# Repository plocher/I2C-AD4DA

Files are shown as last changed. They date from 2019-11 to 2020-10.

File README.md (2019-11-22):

# I2C-AD4DA
## License: CERN Open Hardware Licence v1.2

## Status: mature

I2C 4x A/D 1x  D/A I/O expander based on a PCF8591T

Expansion card that provides four Analog to Digital inputs and one digital to analog output.
I use it to control LED Layout lighting color balances and levels with slide potentiometers.

## Versions:
 * 1.0
 * 1.1
 * 2.0
 * 3.0

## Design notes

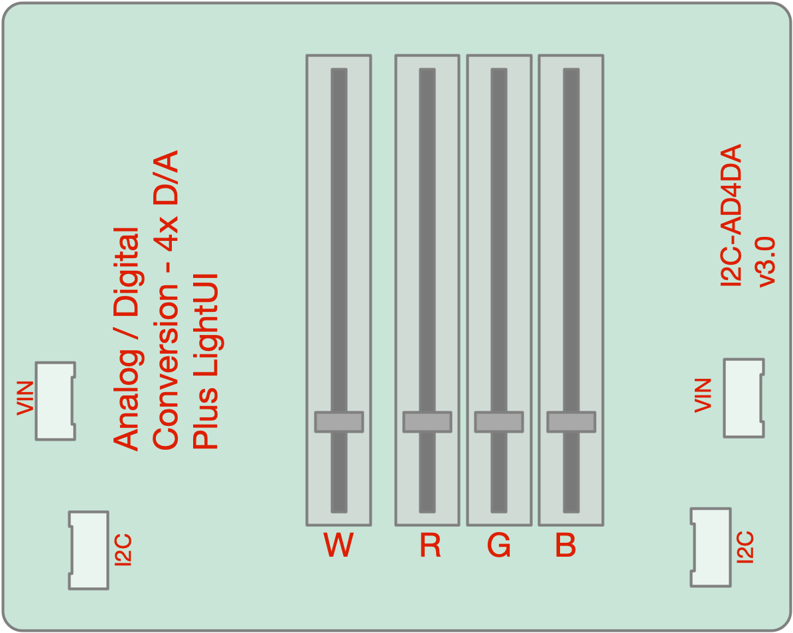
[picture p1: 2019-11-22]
I2C-AD4DA-LightUI-V3-Graphic.png

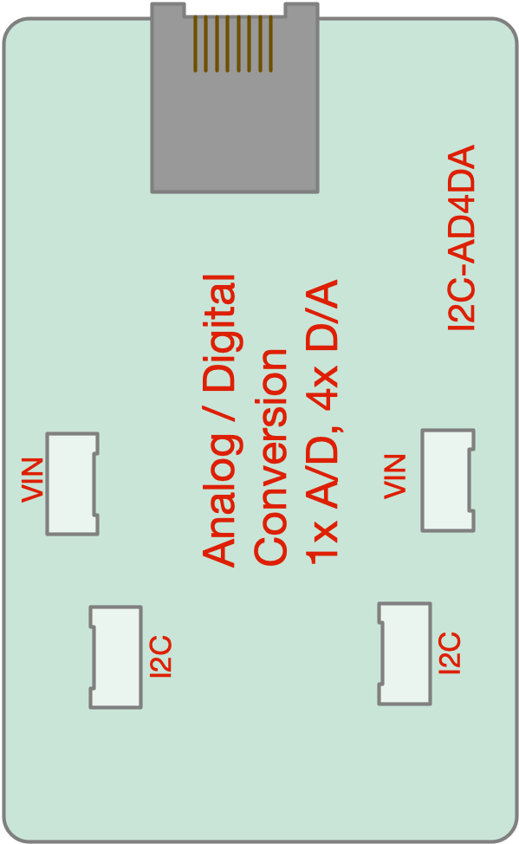
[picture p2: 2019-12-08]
I2C-AD4DA-V2-Graphic.png

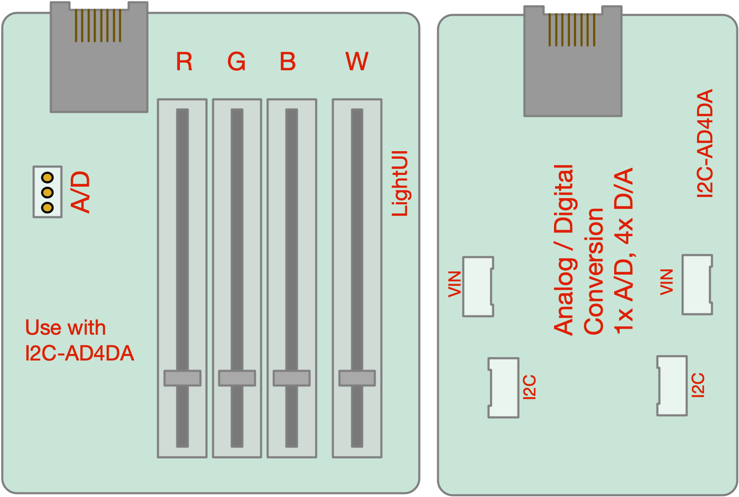
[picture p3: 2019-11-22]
I2C-AD4DA-LightUI-V2-Graphic.png

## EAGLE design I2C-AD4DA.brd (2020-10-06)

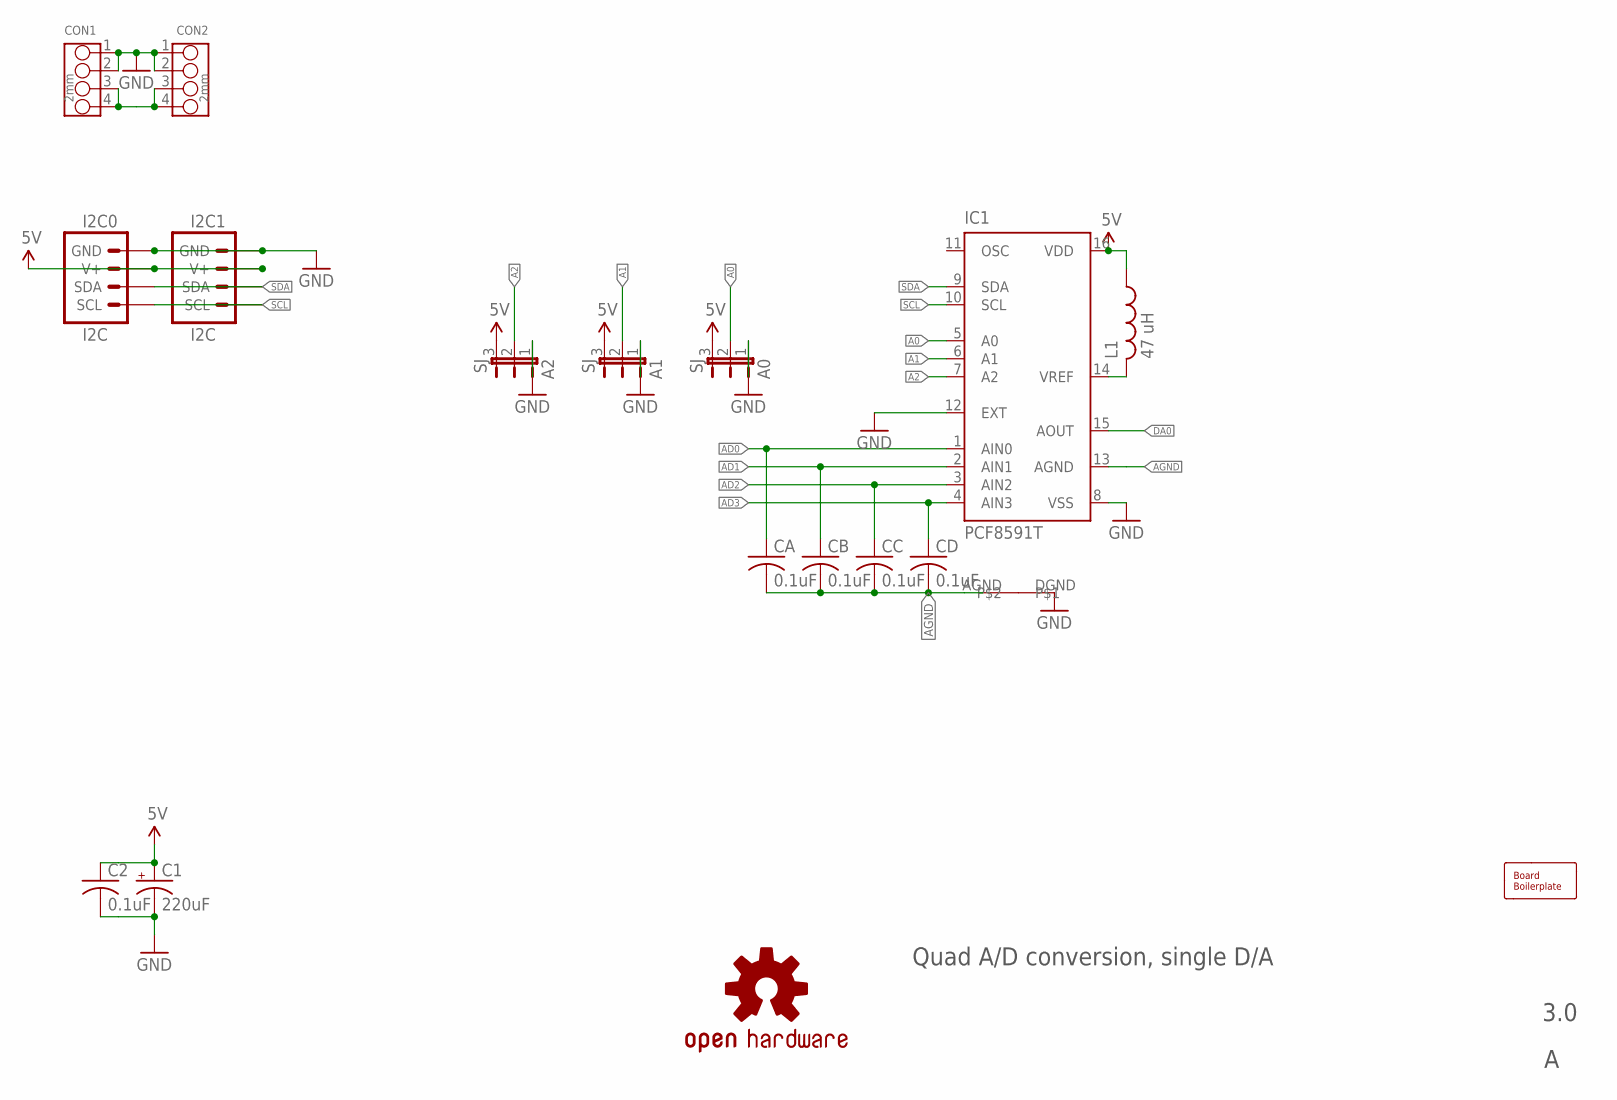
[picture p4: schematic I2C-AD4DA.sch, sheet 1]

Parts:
A0, A1, A2: SJ; SJ_3_PASTE1&2
BOARD1: BOARD; BOARD-DINRAIL-3.17INX10CM
C1: 220uF; 0810-CAP
C2: 0.1uF; 0805-CAP
CA: 0.1uF; 0805-CAP
CB: 0.1uF; 0805-CAP
CC: 0.1uF; 0805-CAP
CD: 0.1uF; 0805-CAP
CON1, CON2: 2mm; 4P-2.0
I2C0, I2C1: I2C; I2C-L
IC1: PCF8591T; SO16W
L1: 47 uH; L2012C
LOGO1: OSHW; OSHW-LOGO-L
U$1: AGND+DGND

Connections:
5V: A0.3, A1.3, A2.3, C1.+, C2.1, I2C0.V+, I2C0.V+@1 (V+), I2C1.V+, I2C1.V+@1 (V+), IC1.16 (VDD), L1.1; also elsewhere on the board
A0: A0.2, IC1.5 (A0)
A1: A1.2, IC1.6 (A1)
A2: A2.2, IC1.7 (A2)
AD0: CA.1, IC1.1 (AIN0); also elsewhere on the board
AD1: CB.1, IC1.2 (AIN1); also elsewhere on the board
AD2: CC.1, IC1.3 (AIN2); also elsewhere on the board
AD3: CD.1, IC1.4 (AIN3); also elsewhere on the board
AGND: CA.2, CB.2, CC.2, CD.2, IC1.13 (AGND), U$1.AGND; also elsewhere on the board
DA0: IC1.15 (AOUT)
GND: A0.1, A1.1, A2.1, C1.-, C2.2, CON1.1, CON1.2, CON2.1, CON2.2, I2C0.GND, I2C0.GND@1 (GND), I2C1.GND, I2C1.GND@1 (GND), IC1.8 (VSS), IC1.12 (EXT), U$1.DGND; also elsewhere on the board
unnamed: IC1.14 (VREF), L1.2
SCL: I2C0.SCL, I2C0.SCL@1 (SCL), I2C1.SCL, I2C1.SCL@1 (SCL), IC1.10 (SCL)
SDA: I2C0.SDA, I2C0.SDA@1 (SDA), I2C1.SDA, I2C1.SDA@1 (SDA), IC1.9 (SDA)
VIN: CON1.3, CON1.4, CON2.3, CON2.4

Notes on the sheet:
Quad A/D conversion, single D/A
3.0

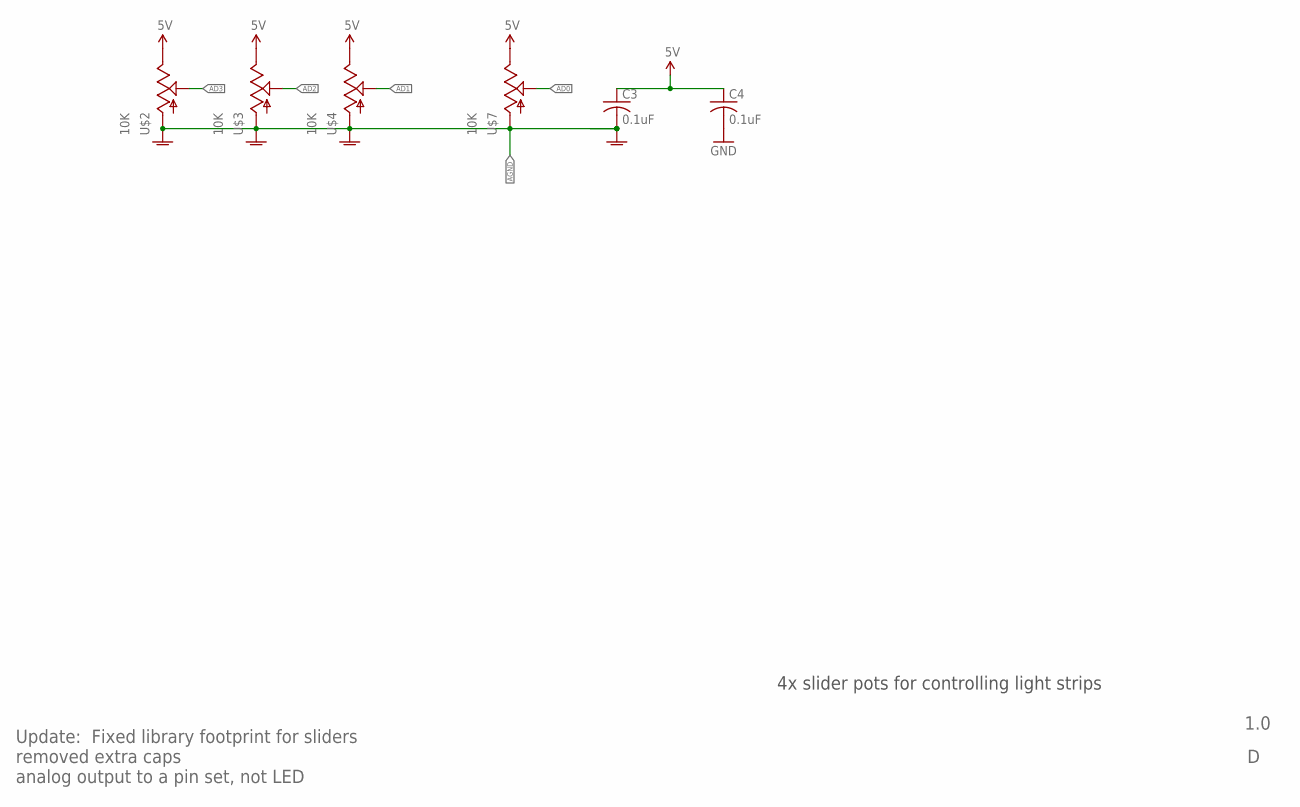
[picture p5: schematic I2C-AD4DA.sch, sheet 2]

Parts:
C3, C4: 0.1uF; 0805-CAP
U$2, U$3, U$4, U$7: 10K; SLIDER-45MM

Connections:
5V: C3.1, C4.1, U$2.E, U$3.E, U$4.E, U$7.E; also elsewhere on the board
AD0: U$7.S; also elsewhere on the board
AD1: U$4.S; also elsewhere on the board
AD2: U$3.S; also elsewhere on the board
AD3: U$2.S; also elsewhere on the board
AGND: C3.2, U$2.A, U$2.AGND@0 (AGND), U$2.AGND@1 (AGND), U$3.A, U$3.AGND@0 (AGND), U$3.AGND@1 (AGND), U$4.A, U$4.AGND@0 (AGND), U$4.AGND@1 (AGND), U$7.A, U$7.AGND@0 (AGND), U$7.AGND@1 (AGND); also elsewhere on the board
GND: C4.2; also elsewhere on the board

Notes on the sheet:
4x slider pots for controlling light strips
1.0
Update: Fixed library footprint for sliders removed extra caps analog output to a pin set, not LED

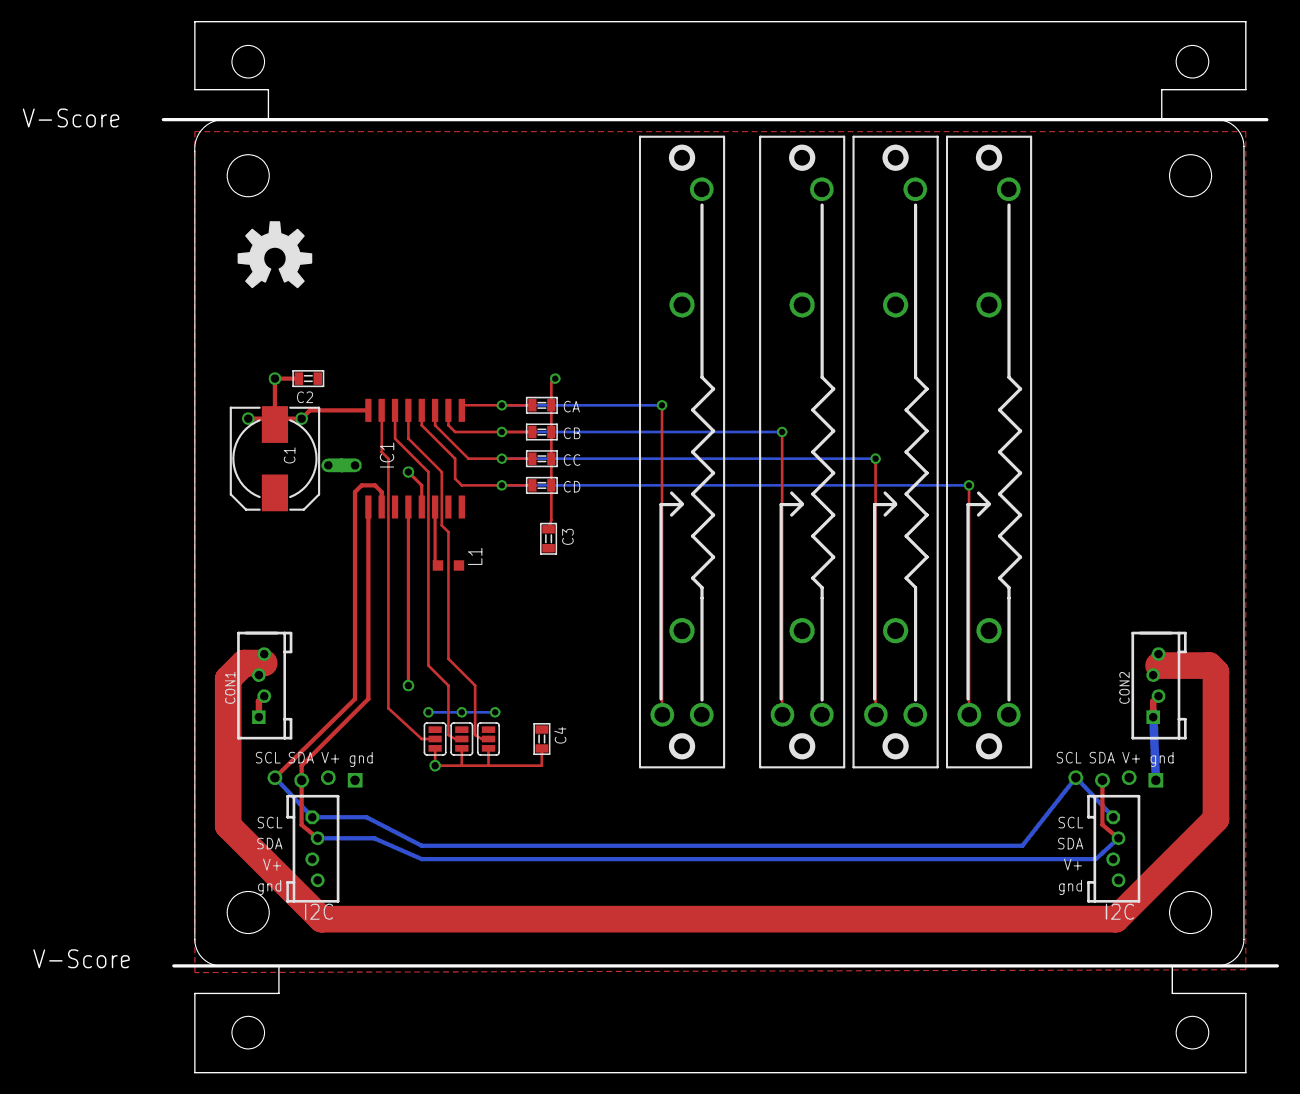
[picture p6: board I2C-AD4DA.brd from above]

Board: 2 copper layers, 106.0 x 100.0 mm, 24 parts (0 on the bottom side), 14 nets.

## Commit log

2020-10-05 added values for connectors
    [I2C-AD4DA.brd, I2C-AD4DA.sch]
2020-10-06 normalized values
    [I2C-AD4DA.brd, I2C-AD4DA.sch]

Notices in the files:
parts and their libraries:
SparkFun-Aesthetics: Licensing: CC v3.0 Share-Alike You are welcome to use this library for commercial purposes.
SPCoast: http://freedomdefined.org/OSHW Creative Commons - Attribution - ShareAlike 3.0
